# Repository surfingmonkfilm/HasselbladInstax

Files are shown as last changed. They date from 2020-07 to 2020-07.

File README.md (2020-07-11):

# HasselbladInstax
For the hosting of project files for the Hasselblad Instaxback created by @SurfingMonkFilm (insta). 

These folders contain all the files needed to recreate the project described on the www.surfingmonk.com site. 

The project is not ready to be followed just yet. This is uploaded for full candidness of our progress so far.

Last Updated 11 Jul 2020.

Any questions should be directed to surfingmonk@protonmail.com in the first instance.

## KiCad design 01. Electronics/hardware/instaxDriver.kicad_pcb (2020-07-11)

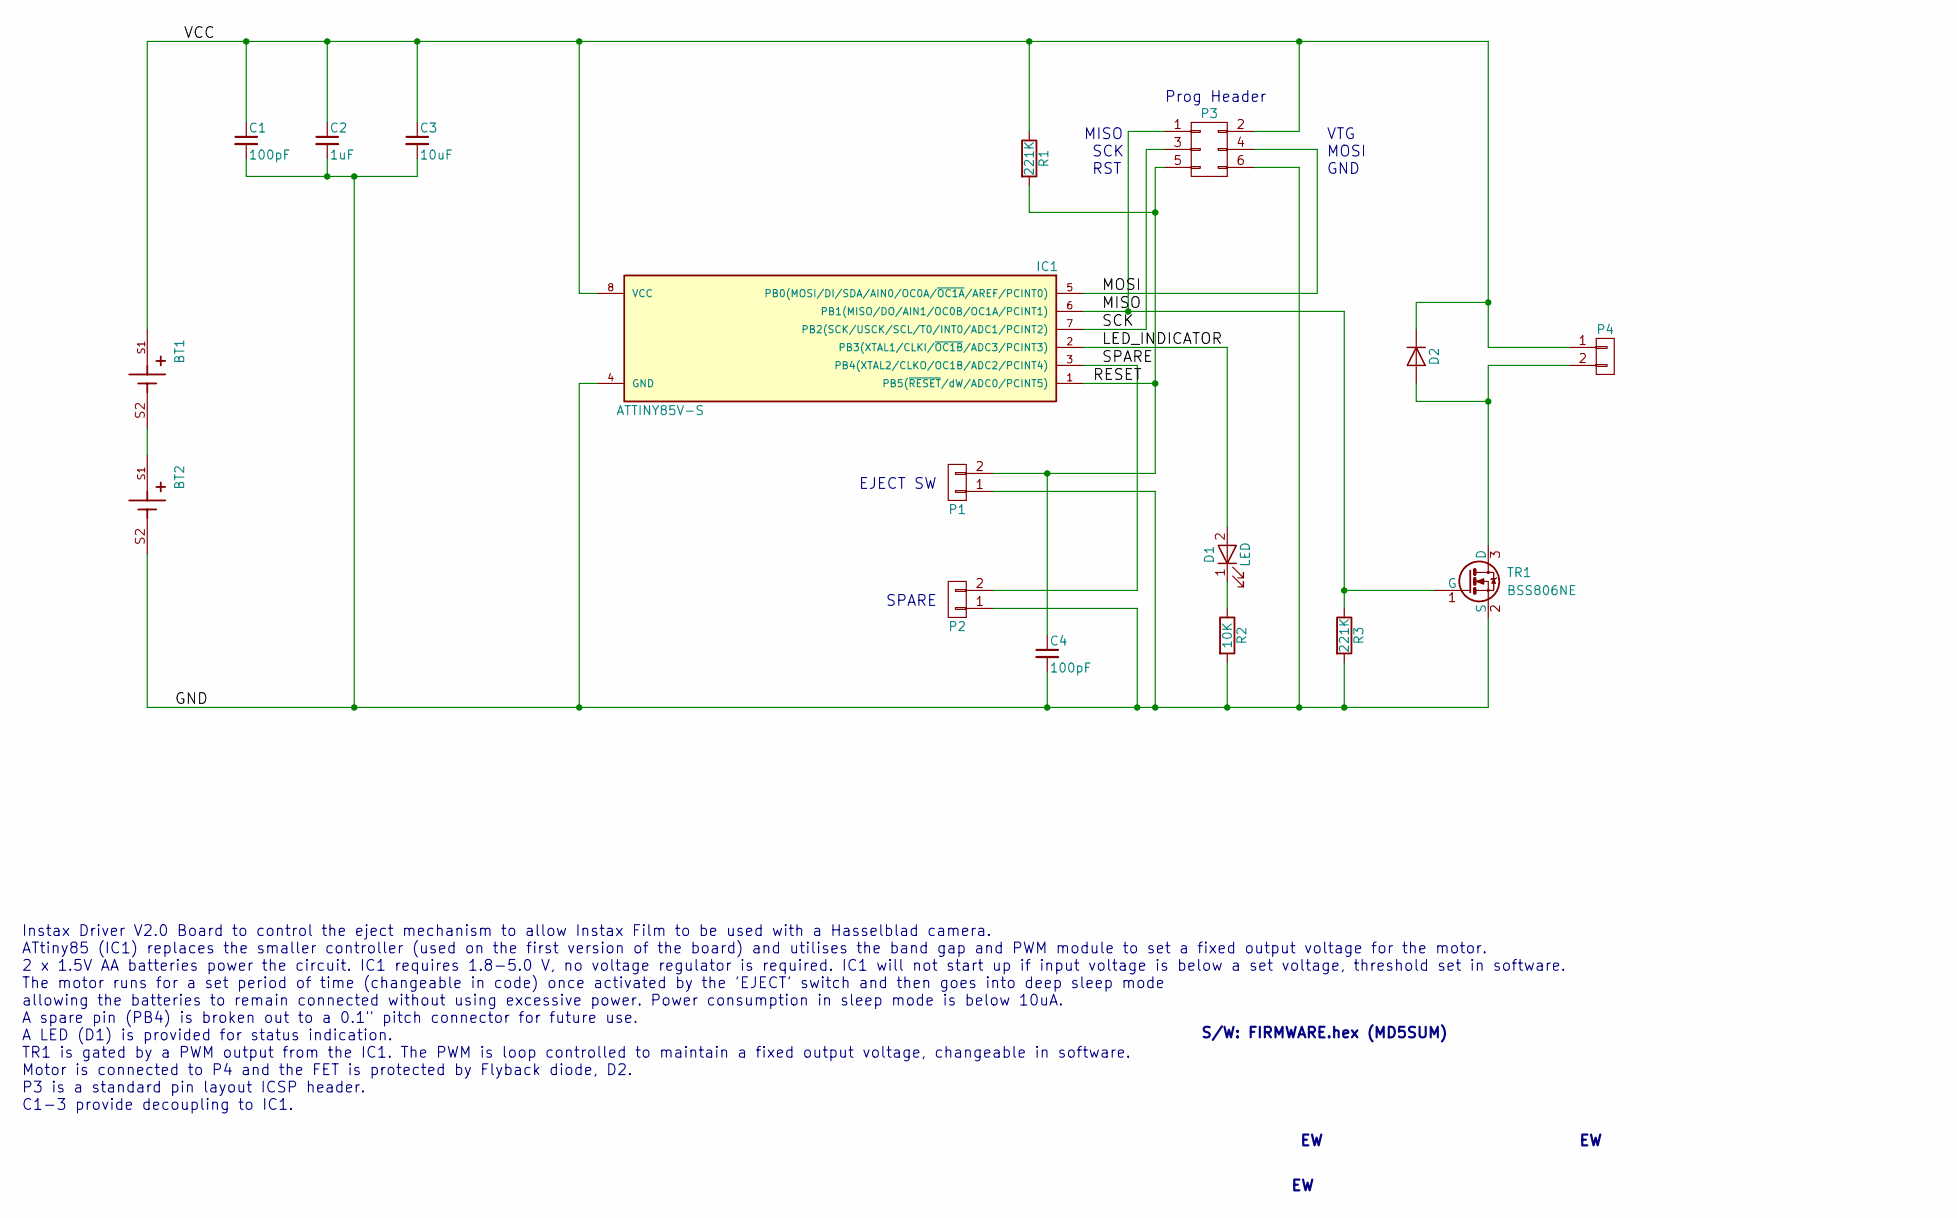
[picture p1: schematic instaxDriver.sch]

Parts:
BT1, BT2: BK-82; BAT_BK-82; ManPartNum 82; Farnell 908721
C1, C4: 100pF; C_0603_HandSoldering; ManPartNum VJ0603A101JXBAC; Farnell 2896678
C2: 1uF; C_0603_HandSoldering; ManPartNum MC0603B105K160CT; Farnell 2320814
C3: 10uF; C_0603_HandSoldering; ManPartNum LMK107BBJ106MALT; Farnell 2113070
D1: LED; LED_0603; ManPartNum 150060AS75020; Farnell 3255534
D2: CD0603-B0240R; D_0603; ManPartNum RB522ES-30T15R; Farnell 3407086
IC1: ATTINY85V-S; SOIC-8_3.9x4.9mm_Pitch1.27mm; Farnell 1455166
P1, P2, P4: CONN_01X02; Socket_Strip_Straight_1x02
P3: CONN_02X03; Socket_Strip_Straight_2x03
R1, R3: 221K; R_0603_HandSoldering; ManPartNum MCWR06X2213FTL; Farnell 2694777
R2: 10K; R_0603_HandSoldering; ManPartNum MCWR06X1002FTL; Farnell 2447230
TR1: BSS806NE; SOT-23_Handsoldering; ManPartNum BSS806NEH6327XTSA1; Farnell 2480654

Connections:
/GND: BT2.S2 (batt_neg), C1.2, C2.2, C3.2, C4.2, IC1.4 (GND), P1.1, P2.1, P3.6, R2.2, R3.2, TR1.2 (S)
/LED_INDICATOR: D1.2 (A), IC1.2 (PB3(XTAL1/CLKI/~OC1B~/ADC3/PCINT3))
/MISO: IC1.6 (PB1(MISO/DO/AIN1/OC0B/OC1A/PCINT1)), P3.1, R3.1, TR1.1 (G)
/MOSI: IC1.5 (PB0(MOSI/DI/SDA/AIN0/OC0A/~OC1A~/AREF/P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), P3.4
/RESET: C4.1, IC1.1 (PB5(~RESET~/dW/ADC0/PCINT5)), P1.2, P3.5, R1.2
/SCK: IC1.7 (PB2(SCK/USCK/SCL/T0/INT0/ADC1/PCINT2)), P3.3
/SPARE: IC1.3 (PB4(XTAL2/CLKO/OC1B/ADC2/PCINT4)), P2.2
/VCC: BT1.S1 (batt_pos), C1.1, C2.1, C3.1, D2.1 (K), IC1.8 (VCC), P3.2, P4.1, R1.1
unnamed: BT1.S2 (batt_neg), BT2.S1 (batt_pos)
unnamed: D1.1 (K), R2.1
unnamed: D2.2 (A), P4.2, TR1.3 (D)

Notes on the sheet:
S/W: FIRMWARE.hex (MD5SUM)
Prog Header
VTG MOSI GND
MISO SCK RST
EJECT SW
SPARE
Instax Driver V2.0 Board to control the eject mechanism to allow Instax Film to be used with a Hasselblad camera. ATtiny85 (IC1) replaces the smaller controller (used on the first version of the board) and utilises the band gap and PWM module to set a fixed output voltage for the motor. 2 x 1.5V AA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

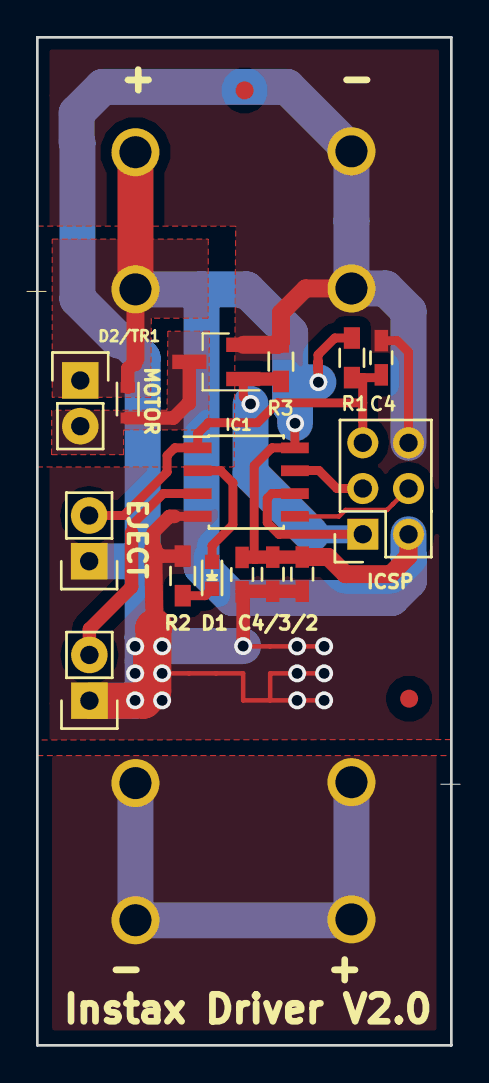
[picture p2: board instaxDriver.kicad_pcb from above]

Board: 2 copper layers, 23.0 x 56.0 mm, 17 parts (0 on the bottom side), 11 nets.

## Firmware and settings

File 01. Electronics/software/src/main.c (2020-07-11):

#include <stdio.h>
#include <stdlib.h>
#include <float.h>
#include <avr/io.h>
#include <avr/iotn85.h> /* don't know why this is required but it is */
#include <util/delay.h>
#include <avr/sleep.h>
#include <avr/power.h>
#include <avr/eeprom.h>
#include <avr/interrupt.h>
#include <avr/wdt.h>
#include "main.h"

/* DEFINES for run time and Soft start*/
#define RUN_TIME 4000 /* time in ms for the motor to run */
#define TIME_DIV 1
#define RUN_TIME_STEPS (RUN_TIME/TIME_DIV)
#define SS_step 10

/* TARGET MOTOR VOLTAGE */
#define MOTOR_VOLTAGE 2600

float EEMEM ref = 1.13016796875;


/*
 * PB0	-	IN	- unused
 * PB1	-	OUT	- PWM Motor
 * PB2	-	OUT	- LED
 * PB3	-	IN	- VREG OUTPUT - Read Analog in
 * PB4	- 	OUT	- VRGE IPUT - Use a digital out to power regulator to use a VRef
 * PB5	-	IN	- RESET pin - Used to wait the chip from sleep (also debug Wire)
 */

static FILE outStream = FDEV_SETUP_STREAM(usart_putc, NULL, _FDEV_SETUP_WRITE);
double VrefCalib = 0;

int main() {

	VrefCalib = eeprom_read_float(&ref);

	/* bind the usart to stdout */
	stdout = &outStream;

	/* initialise chip */
	DDRB = 0b010111; /* 0, 1, 2, 4 are out puts for UART, PWM, LED, VRef respectively */
	PORTB = 0b100000;

	/* this is timing critical. Set prescaler: CLK 1MHz */
//	CLKPR = 0b10000000;
//	CLKPR = 0b00000011;

	printf("\nInstax Driver V2.0 initialised\n");

	/* determine how the chip was turned on */
	/* this is run if the chip is just turned on for the first time */
	if (!(MCUSR & (1 << EXTRF))) {
		goto imout;
	}
	MCUSR = 0;

	uint16_t counterStop = 0; /* this is the timer for the stop in case the stop button never actuates. Times out after 25s. */
	uint8_t currentPWM = 0;
	while ((counterStop < RUN_TIME_STEPS)) {
		uint16_t test2 = readADC();
		double vcc = (VrefCalib / (((double) (test2)) / 1024.00)) * 1000.00;
		uint8_t pwm_out = ((double) (MOTOR_VOLTAGE) / (double) (vcc)) * 255;

		if (currentPWM < pwm_out) {
			currentPWM += SS_step;
			pwm(currentPWM);
		}

		/* just in case we get overshoot */
		if (currentPWM > pwm_out) {
			pwm(currentPWM--);
		}

		/*printf("%d, %d, %d, %d\n", (uint16_t)vcc, pwm_out, currentPWM, counterStop); */

		counterStop++;
		_delay_ms(TIME_DIV);
	}

	/*  go to deep deep sleep */
	imout:
		cli();
		DDRB = 0x0;
		PORTB = 0x00;
		ADCSRA = 0;
		ADCSRB = 0;
		ADCSRA &= ~(1<<ADEN);
		power_adc_disable();
		power_timer0_disable();
		power_timer1_disable();
		power_usi_disable();
		PRR = 0xFF;

		MCUSR = 0x00;
		WDTCR |= (1<<WDCE) | (1<<WDE);
		WDTCR = 0x00;

		set_sleep_mode(SLEEP_MODE_PWR_DOWN);
		sleep_enable();
		sleep_cpu();
		sleep_mode();

}

void pwm(uint8_t val) {
	OCR1C = 255; /*  max value */
	PLLCSR = 0b10000110; // this could be changed to use 32MHz and set use PLL as clock source.
	TCCR1 = 0b11100001;
	OCR1A = val;
}

uint16_t readADC() {

	uint8_t adc_lobyte;
	uint16_t raw_adc;

	ADMUX = (0 << ADLAR) | /*  do not left shift result (for 10-bit values) */
	(0 << REFS2) | /* Sets ref. voltage to Vcc, bit 2 */
	(0 << REFS1) | /* Sets ref. voltage to Vcc, bit 1 */
	(0 << REFS0) | /* Sets ref. voltage to Vcc, bit 0 */
	(1 << MUX3) | /* use ADC2 for input (bg), MUX bit 3 */
	(1 << MUX2) | /* use ADC2 for input (bg), MUX bit 2 */
	(0 << MUX1) | /* use ADC2 for input (bg), MUX bit 1 */
	(0 << MUX0); /* use ADC2 for input (bg), MUX bit 0 */

	ADCSRA = (1 << ADEN) | /* Enable ADC */
	(1 << ADPS2) | /* set prescaler to 16, bit 2 */
	(0 << ADPS1) | /* set prescaler to 16, bit 1 */
	(0 << ADPS0); /* set prescaler to 16, bit 0 */

	ADCSRA |= (1 << ADSC);
	while (ADCSRA & (1 << ADSC))
		;

	adc_lobyte = ADCL;
	raw_adc = ADCH << 8 | adc_lobyte;
	return (raw_adc);

}

uint8_t usart_putc(char val) {

	if (val == '\n')
		usart_putc('\r');

	PORTB |= 0b1; /* start by setting the output pin high, this is the start state */
	_delay_us(1000); /* wait for a bit */
	PORTB = PORTB & 0b111110; /* drop line to start tx */
	_delay_us(833); /* delay for 1200 baud */
	uint8_t i = 0;
	for (i = 0; i < 8; i++) {
		if (val & (0b1 << i)) {
			PORTB |= 0b1; /* start by setting the output pin high, this is the start state */
		} else {
			PORTB = PORTB & 0b111110; /* drop line to start tx */
		}
		_delay_us(833);
	}

	PORTB |= 0b1; /* always finish by restoring pin to its starting state */
	_delay_us(1000);
	return (0);
}

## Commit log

2020-07-01 Add electronic design files (hardware and software)
    [instaxDriver-B.Cu.gbr, instaxDriver-B.Mask.gbr, instaxDriver-B.SilkS.gbr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]
2020-07-01 removed old files
    [instaxDriver-B.Cu.gbr, instaxDriver-B.Mask.gbr, instaxDriver-B.SilkS.gbr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]
